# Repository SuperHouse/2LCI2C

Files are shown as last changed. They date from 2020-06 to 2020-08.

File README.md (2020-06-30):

2 x Load Cell I2C Interface
===========================
Copyright 2020 SuperHouse Automation Pty Ltd <www.superhouse.tv>  
Designed by Jonathan Oxer

A pair of load cell amplifiers with an ATTiny84 microcontroller to
provide an I2C interface to the load cells.

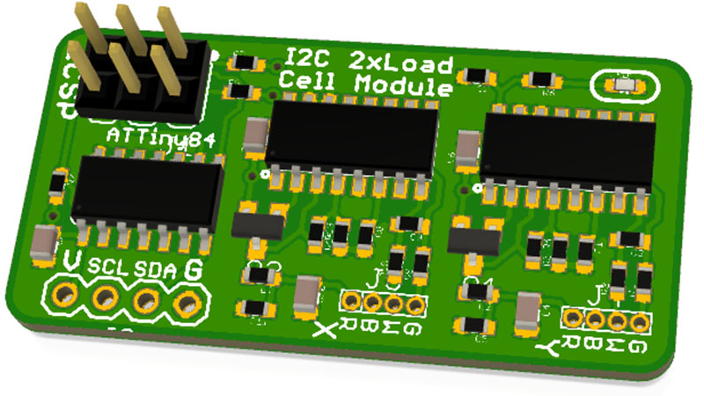
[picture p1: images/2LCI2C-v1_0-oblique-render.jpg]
PCB render


Features:

 * 2 x load cell interfaces
 * I2C connection

More information is available at:

  http://www.superhouse.tv/2lci2c

INSTALLATION
------------
The design is saved as an EAGLE project. EAGLE PCB design software is
available from www.cadsoftusa.com free for non-commercial use. To use
this project download it and place the directory containing these files
into the "eagle" directory on your computer. Then open EAGLE and
navigate to the project.

DISTRIBUTION
------------
The specific terms of distribution of this project are governed by the
license referenced below.

LICENSE
-------
Licensed under the TAPR Open Hardware License (www.tapr.org/OHL).
The "license" folder within this repository also contains a copy of
this license in plain text format.

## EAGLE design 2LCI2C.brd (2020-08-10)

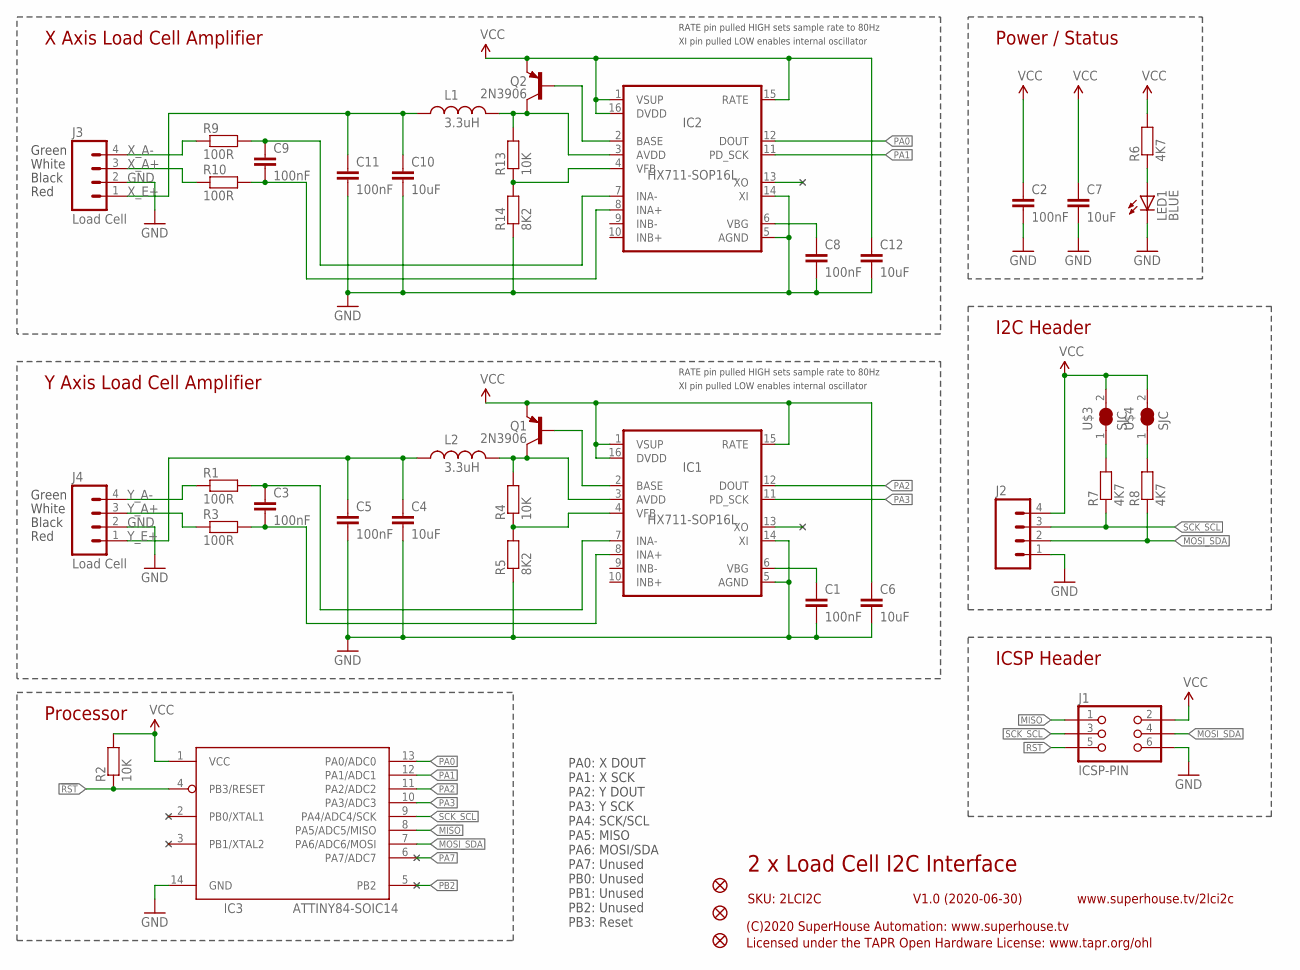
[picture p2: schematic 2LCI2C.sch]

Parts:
C1, C2, C3, C5, C8, C9, C11: 100nF; C0603
C4, C6, C7, C10, C12: 10uF; C0805
IC1, IC2: HX711-SOP16L; SOP16-L
IC3: ATTINY84-SOIC14; SOIC14
J1: ICSP-PIN; 2X03-ICSP
J2: M04-PLAIN; 1X04
J3, J4: Load Cell; 1X04-1.27-PLAIN
L1, L2: 3.3uH; L0603
LED1: BLUE; LED-0603
Q1, Q2: 2N3906; SOT23-BEC
R1, R3, R9, R10: 100R; R0603
R2, R4, R13: 10K; R0603
R5, R14: 8K2; R0603
R6, R7, R8: 4K7; R0603
U$3, U$4: SJC
U$5, U$10, U$11: FIDUCIAL1X2.5; FIDUCIAL-1X2.5

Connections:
!RST: IC3.4 (PB3/RESET), J1.5, R2.1
GND: C1.2, C2.2, C4.2, C5.2, C6.2, C7.2, C8.2, C10.2, C11.2, C12.2, IC1.5 (AGND), IC1.14 (XI), IC2.5 (AGND), IC2.14 (XI), IC3.14 (GND), J1.6, J2.1, J3.2, J4.2, LED1.C, R5.1, R14.1
MISO: IC3.8 (PA5/ADC5/MISO), J1.1
MOSI_SDA: IC3.7 (PA6/ADC6/MOSI), J1.4, J2.2, R8.1
unnamed: C3.1, IC1.7 (INA-), R1.2
unnamed: C3.2, IC1.8 (INA+), R3.2
unnamed: C1.1, IC1.6 (VBG)
unnamed: IC1.2 (BASE), Q1.B
unnamed: LED1.A, R6.1
unnamed: IC1.4 (VFB), R4.1, R5.2
unnamed: IC1.3 (AVDD), L2.2, Q1.C, R4.2
unnamed: R7.2, U$3.1
unnamed: R8.2, U$4.1
unnamed: C9.1, IC2.7 (INA-), R9.2
unnamed: C9.2, IC2.8 (INA+), R10.2
unnamed: IC2.3 (AVDD), L1.2, Q2.C, R13.2
unnamed: C8.1, IC2.6 (VBG)
unnamed: IC2.2 (BASE), Q2.B
unnamed: IC2.4 (VFB), R13.1, R14.2
PA0: IC2.12 (DOUT), IC3.13 (PA0/ADC0)
PA1: IC2.11 (PD_SCK), IC3.12 (PA1/ADC1)
PA2: IC1.12 (DOUT), IC3.11 (PA2/ADC2)
PA3: IC1.11 (PD_SCK), IC3.10 (PA3/ADC3)
PA7: IC3.6 (PA7/ADC7)
PB2: IC3.5 (PB2)
SCK_SCL: IC3.9 (PA4/ADC4/SCK), J1.3, J2.3, R7.1
VCC: C2.1, C6.1, C7.1, C12.1, IC1.1 (VSUP), IC1.15 (RATE), IC1.16 (DVDD), IC2.1 (VSUP), IC2.15 (RATE), IC2.16 (DVDD), IC3.1 (VCC), J1.2, J2.4, Q1.E, Q2.E, R2.2, R6.2, U$3.2, U$4.2
X_A+: J3.3, R10.1
X_A-: J3.4, R9.1
X_E+: C10.1, C11.1, J3.1, L1.1
Y_A+: J4.3, R3.1
Y_A-: J4.4, R1.1
Y_E+: C4.1, C5.1, J4.1, L2.1

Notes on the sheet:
2 x Load Cell I2C Interface
V1.0 (2020-06-30)
SKU: 2LCI2C
(C)2020 SuperHouse Automation: www.superhouse.tv
Licensed under the TAPR Open Hardware License: www.tapr.org/ohl
www.superhouse.tv/2lci2c
Power / Status
PA0: X DOUT PA1: X SCK PA2: Y DOUT PA3: Y SCK PA4: SCK/SCL PA5: MISO PA6: MOSI/SDA PA7: Unused PB0: Unused PB1: Unused PB2: Unused PB3: Reset
X Axis Load Cell Amplifier
RATE pin pulled HIGH sets sample rate to 80Hz
Y Axis Load Cell Amplifier
XI pin pulled LOW enables internal oscillator
I2C Header
Processor
ICSP Header
Red
Black
White
Green

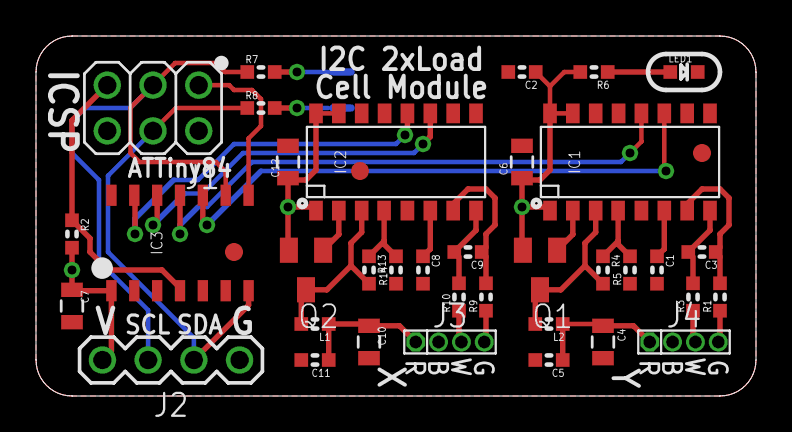
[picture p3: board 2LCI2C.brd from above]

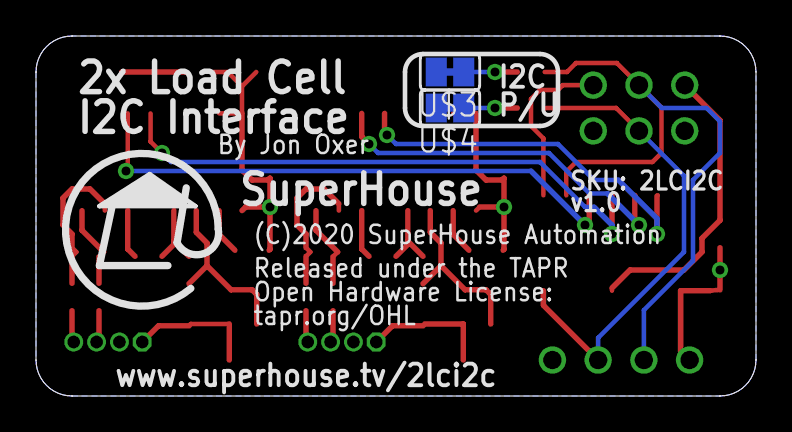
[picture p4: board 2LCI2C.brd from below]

Board: 2 copper layers, 40.0 x 20.0 mm, 41 parts (2 on the bottom side), 31 nets.

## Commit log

2020-06-30 Version 1.0 release
    [2LCI2C.brd, 2LCI2C.sch, ZEROSTICK.brd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]
2020-07-02 Changed sample rate from 10Hz to 80Hz
    [2LCI2C.brd, 2LCI2C.sch]
2020-07-06 Added fiducials for re-release v1.0
    [2LCI2C.brd, 2LCI2C.sch]
